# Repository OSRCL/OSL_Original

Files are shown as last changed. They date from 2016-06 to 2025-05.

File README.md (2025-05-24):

# Open Source RC Lights
(aka, "OSL")

OSL Board Assembled OSL Board

**--> [INSTRUCTIONS & DOCUMENTATION AVAILABLE HERE](https://openpanzer.org/wiki/doku.php?id=wiki:otherprojects:osl) <--**

OSL is an Arduino-based, open source project for controlling lights in RC cars and trucks. It uses an ATmega328 as the processor and has 8 light outputs. All the components on the board are through-hole which makes it easy to assemble and solder. 
 
Some features: 
  * Control up to 8 light circuits
  * Accepts three channels of RC input (throttle, steering, and an optional 3rd channel)
  * Each light can respond to various model **States**: forward, reverse, stopped, stopped after delay, braking, right turn, left turn, no turn, accelerating, decelerating, and any of up to 5 positions for the channel 3 switch if attached. 
  * For each light in each State the **Setting** defines the behavior of the light: on, off, fade on, fade off, blink, fast blink, safety blink (and the alternate versions of blink, fast blink, and safety blink), soft blink, dim, xenon-on effect, or backfire effect.
  * The collection of all Settings for all lights in all States is called a **Scheme**. Multiple schemes can be defined and you can switch between them from your transmitter.
  * Schemes and other operating adjustments are made in the free Arduino IDE. Everything is well explained and you don't need to know how to write code.
  * Works with both 5 and 6 volt RC systems
<br/>

## Resources  
  * [OSL Wiki](https://openpanzer.org/wiki/doku.php?id=wiki:otherprojects:osl)
  * [RC Groups Discussion Thread](http://www.rcgroups.com/forums/showthread.php?t=1539753)
  * [Complete collection of resources and downloads](https://openpanzer.org/downloads#OSL)
<br/>

## OSL Hardware
**Board version 1.7**  
See the "hardware" folder in this repository for Eagle board files, schematic, and bill of materials. 
  * [Printable Schematic](https://www.openpanzer.org/secure_downloads/osl/eagle/OpenSourceLights_v17_Schematic.pdf) (PDF)
  * [Bill of Materials](https://www.openpanzer.org/secure_downloads/osl/bom/OpenSourceLights_BOM.pdf) (PDF)
  * [Purchase PCBs at OSH Park](https://oshpark.com/shared_projects/kmCzNipk)
  * [Other user designs](https://www.openpanzer.org/forum/index.php?page=osl_other)
<br/>

## Getting Started with Arduino
First you will need to install the Arduino IDE on your computer, [you can download it from here](https://www.arduino.cc/en/software).

Next download the OSL source files (Arduino calls this a "sketch"). Click the green "Clone or Download" button at the top of this page, then select "Download ZIP." 

1. Unzip the download and put the folder named “OpenSourceLights” into your Arduino “Sketches” folder. This may be a location you specified or it may be the default location that Arduino chose when you installed the IDE. If you are unsure where Arduino thinks your Sketches folder is:
   - Open the Arduino IDE
   - Go to File -> Preferences
   - At the top of the popup screen that appears, look at the path under the heading "Sketchbook location". This shows you where your Sketches folder is. 

2. Open the sketch through the IDE or just by clicking on any of the .ino files in the OpenSourceLights folder. Now let's make sure the IDE is setup to compile the project correctly:
   - In the IDE, go to the Tools menu and select Board -> Arduino AVR Boards -> "Arduino Nano." In fact several boards would work, but "Nano" is the easiest to remember.
   - Make sure we have the correct processor selected. Go to Tools -> Processor -> and select "ATmega328P". **Note:** Some users may need to select "Atmega328P (Old Bootloader)" if they have problems loading the sketch onto their device.

3. Compile. This is done by clicking the checkmark button at the top left of the IDE window, or by going to the Sketch menu and clicking "Verify/Compile." The IDE will run for a few moments then give you the results of the compilation at the bottom of the screen. If successful, you are ready to modify the sketch so that it does what you want! Read this page in the OSL Wiki for more information: [Modifying the Sketch](https://openpanzer.org/wiki/doku.php?id=wiki:otherprojects:osl:sketch)

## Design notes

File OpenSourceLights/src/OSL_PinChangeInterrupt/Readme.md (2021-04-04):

PinChangeInterrupt Library 1.2.8
================================

Header Picture

PinChangeInterrupt library with a resource friendly implementation (API and LowLevel).
PinChangeInterrupts are different than normal Interrupts. See detail below.

##### Features:
* PinChangeInterrupt for a lot of pins
* Rising, Falling or Change detection for every pin separately
* Usable on a lot Arduino compatible boards
* Implementation is fast, compact and resource friendly
* Ports/Pins can be manually deactivated in the Settings file
* API and LowLevel option
* Full Port0-3 support
* .a linkage optimization (Arduino IDE)

<a href="https://www.buymeacoffee.com/nicohood">Buy Me A Coffee</a>

#### Supported pins for PinChangeInterrupt:
See [PCINT pin table](https://github.com/NicoHood/PinChangeInterrupt/#pinchangeinterrupt-table) at the bottom for more details.

```
Arduino Uno/Nano/Mini: All pins are usable
Arduino Mega: 10, 11, 12, 13, 50, 51, 52, 53, A8 (62), A9 (63), A10 (64),
           A11 (65), A12 (66), A13 (67), A14 (68), A15 (69)
Arduino Leonardo/Micro: 8, 9, 10, 11, 14 (MISO), 15 (SCK), 16 (MOSI)
HoodLoader2: All (broken out 1-7) pins are usable
Attiny 24/44/84: All pins are usable
Attiny 25/45/85: All pins are usable
Attiny 13: All pins are usable
Attiny 441/841: All pins are usable
ATmega644/ATmega644P/ATmega1284P: All pins are usable
ATmega 162: PORTA and PORTC usable
```

Contact information can be found here:

www.nicohood.de

Installation
============

Download the zip, extract and remove the "-master" of the folder.
Install the library [as described here](http://arduino.cc/en/pmwiki.php?n=Guide/Libraries).

This library can also be used with the [DMBS AVR Library Collection](https://github.com/NicoHood/avr) and a pure makefile.

How to use
==========

It is important that you know at least the basic difference between **PinInterrupts** and **PinChangeInterrupts**.
I will explain the basics of **PinChangeInterrupts** (PCINTs) based on an Arduino Uno.

On a standard Arduino Uno Pin 2 and 3 have **PinInterrupts**. Those are exclusively for a single pin and can detect RISING, FALLING and CHANGE.

**PinChangeInterrupts** instead are used for a whole port (they should have better named them PortChangeInterrupts) and can only detect CHANGE for a whole port.
Each pin row (0-7, 8-13, A0-A5) represents a port. If an interrupt (ISR) occurs on one pin of a port
it is still unclear what pin of the port caused this interrupt. Therefore this library saves the state of the whole port and compares with the last state.
This way we can also see if it was a RISING or FALLING edge instead of only knowing the CHANGE.

A **PinChangeInterrupt** will only be triggered for the attached pins per port.
Meaning if you set PCINT for a pin and another pin on the same port is changing a lot
it will not interrupt your code.

**PinChangeInterrupts** might be a tiny bit slower and not that reliable because of that detection overhead (talking about micro seconds).
Make sure to not use longer function calls inside the ISR or Serial print.
You have the same issues on normal **PinInterrupts** and interrupts in general.

The library is coded to get maximum speed and minimum code size. The LowLevel example without the API takes 4uS to enter the interrupt function in the worst case
which is pretty good and might be even better than the **PinInterrupt** code from the official Arduino core due to high optimization.
If you need very precise interrupts you better use **PinInterrupts** without the Arduino IDE at all.

### Examples
To see how the code works just check the Led and TickTock example.
The LowLevel example is for advanced users with more optimization and more direct access.
The HowItWorks example shows the basic PinChangeInterrupt setup and decoding routine, similar to the library.
See the notes in the examples about more details.

An useful "real use" example of the PinChangeInterrupt library can be found here:
https://github.com/NicoHood/IRLremote

### API Reference

##### Attach a PinChangeInterrupt
```cpp
// The pin has to be a PCINT number. Use the makro to convert a pin to a PCINT number.
// Enables event functions which need to be defined in the sketch.
// Valid interrupt modes are: RISING, FALLING or CHANGE
attachPinChangeInterrupt(digitalPinToPinChangeInterrupt(pinTick), tick, RISING);

// You can also input the PCINT number (see table below)
attachPinChangeInterrupt(5, tock, FALLING);

// PinChangeInterrupt can always be abbreviated with PCINT
attachPCINT(digitalPinToPCINT(pinBlink), blinkLed, CHANGE);
```

##### Detach a PinChangeInterrupt
```cpp
// Similar usage as the attachPCINT function.
// Interrupts will no longer occur.
detachPinChangeInterrupt(digitalPinToPinChangeInterrupt(pinTick));
detachPinChangeInterrupt(5);
detachPCINT(digitalPinToPCINT(pinTock));
```

##### Enable/Disable a PinChangeInterrupt
```cpp
// Similar usage as the attachPCINT function.
// Use this to temporary enable/disable the Interrupt
disablePinChangeInterrupt(digitalPinToPinChangeInterrupt(pinTick));
disablePinChangeInterrupt(5);
disablePCINT(digitalPinToPCINT(pinBlink));

// Enable the PCINT with the old settings again (function + mode)
enablePinChangeInterrupt(digitalPinToPinChangeInterrupt(pinTick));
enablePinChangeInterrupt(5);
enablePCINT(digitalPinToPCINT(pinBlink));
```

##### Get Trigger on mode CHANGE
```cpp
// Differenciate between RISING and FALLING on mode CHANGE.
// Only use this in the attached interrupt function.
uint8_t trigger = getPinChangeInterruptTrigger(digitalPinToPCINT(pinTick));
if(trigger == RISING)
  // Do something
else if(trigger == FALLING)
  // Do something
else
  // Wrong usage (trigger == CHANGE)
```

##### LowLevel API
See [LowLevel example](examples/PinChangeInterrupt_LowLevel/PinChangeInterrupt_LowLevel.ino) for more details.
```cpp
// Use the attach function as you are used to, just leave out the function name
attachPinChangeInterrupt(interruptBlink, CHANGE);

// LowLevel function that is called when an interrupt occurs for a specific PCINT.
// It is required to know the exact PCINT number, no Arduino pin number will work here.
void PinChangeInterruptEvent(5)(void) {
  // Do something
}
```

PinchangeInterrupt Table
========================
Pins with * are not broken out/deactivated by default.
You may activate them in the setting file (advanced).

Each row section represents a port(0-3).
Not all MCUs have all Ports/Pins physically available.

#### Official Arduinos
```
| PCINT |  Uno/Nano/Mini  |   Mega/2560    | Leonardo/Micro | HL2 (8/16/32u2) |
| ----- | --------------- | -------------- | -------------- | --------------- |
|     0 |  8       (PB0)  | 53 SS   (PB0)  |    SS   (PB0)* |  0 SS   (PB0)*  |
|     1 |  9       (PB1)  | 52 SCK  (PB1)  |    SCK  (PB1)  |  1 SCK  (PB1)   |
|     2 | 10 SS    (PB2)  | 51 MOSI (PB2)  |    MOSI (PB2)  |  2 MOSI (PB2)   |
|     3 | 11 MISO  (PB3)  | 50 MISO (PB3)  |    MISO (PB3)  |  3 MISO (PB3)   |
|     4 | 12 MOSI  (PB4)  | 10      (PB4)  |  8/A8   (PB4)  |  4      (PB4)   |
|     5 | 13 SCK   (PB5)  | 11      (PB5)  |  9/A9   (PB5)  |  5      (PB5)   |
|     6 |    XTAL1 (PB6)* | 12      (PB6)  | 10/A10  (PB6)  |  6      (PB6)   |
|     7 |    XTAL2 (PB7)* | 13      (PB7)  | 11      (PB7)  |  7      (PB7)   |
| ----- | --------------- | -------------- | -------------- | --------------- |
|     8 | A0       (PC0)  |  0 RX   (PE0)* |                |         (PC6)*  |
|     9 | A1       (PC1)  | 15 RX3  (PJ0)* |                |         (PC5)*  |
|    10 | A2       (PC2)  | 14 TX3  (PJ1)* |                |         (PC4)*  |
|    11 | A3       (PC3)  |    NC   (PJ2)* |                |         (PC2)*  |
|    12 | A4 SDA   (PC4)  |    NC   (PJ3)* |                |         (PD5)*  |
|    13 | A5 SDC   (PC5)  |    NC   (PJ4)* |                |                 |
|    14 |    RST   (PC6)* |    NC   (PJ5)* |                |                 |
|    15 |                 |    NC   (PJ6)* |                |                 |
| ----- | --------------- | -------------- | -------------- | --------------- |
|    16 |  0 RX    (PD0)  | A8      (PK0)  |                |                 |
|    17 |  1 TX    (PD1)  | A9      (PK1)  |                |                 |
|    18 |  2 INT0  (PD2)  | A10     (PK2)  |                |                 |
|    19 |  3 INT1  (PD3)  | A11     (PK3)  |                |                 |
|    20 |  4       (PD4)  | A12     (PK4)  |                |                 |
|    21 |  5       (PD5)  | A13     (PK5)  |                |                 |
|    22 |  6       (PD6)  | A14     (PK6)  |                |                 |
|    23 |  7       (PD7)  | A15     (PK7)  |                |                 |
| ----- | --------------- | -------------- | -------------- | --------------- |
```

#### Atmel Attinys
```
| PCINT |   Attiny13   |    Attiny x4    |   Attiny x5   |     Attiny x41      |
| ----- | ------------ | --------------- | ------------- | ------------------- |
|     0 | 0 MOSI (PB0) |  0       (PA0)  | 0 MOSI  (PB0) | A0/D0         (PA0) |
|     1 | 1 MISO (PB1) |  1       (PA1)  | 1 MISO  (PB1) | A1/D1         (PA1) |
|     2 | 2 SCK  (PB2) |  2       (PA2)  | 2 SCK   (PB2) | A2/D2         (PA2) |
|     3 | 3      (PB3) |  3       (PA3)  | 3 XTAL1 (PB3) | A3/D3         (PA3) |
|     4 | 4      (PB4) |  4 SCK   (PA4)  | 4 XTAL2 (PB4) | A4/D4         (PA4) |
|     5 | 5 RST  (PB5) |  5 MISO  (PA5)  | 5 RST   (PB5) | A5/D5   PWM   (PA5) |
|     6 |              |  6 MOSI  (PA6)  |               | A7/D7   PWM   (PA6) |
|     7 |              |  7       (PA7)  |               | A6/D6   PWM   (PA7) |
| ----- | ------------ | --------------- | ------------- | ------------------- |
|     8 |              | 10 XTAL1 (PB0)* |               | A10/D10 XTAL1 (PB0) |
|     9 |              |  9 XTAL2 (PB1)* |               | A9/D9   XTAL2 (PB1) |
|    10 |              |  8 INT0  (PB2)* |               | A8/D8   PWM   (PB2) |
|    11 |              |    RST   (PB3)* |               |         RST   (PB3) |
|    12 |              |                 |               |                     |
|    13 |              |                 |               |                     |
|    14 |              |                 |               |                     |
|    15 |              |                 |               |                     |
| ----- | ------------ | --------------- | ------------- | ------------------- |
```

#### Other Atmel MCUs
```
| PCINT | ATmega644P/1284P  |
| ----- | ----------------- |
|     0 | A0/D24      (PA0) |
|     1 | A1/D25      (PA1) |
|     2 | A2/D26      (PA2) |
|     3 | A3/D27      (PA3) |
|     4 | A4/D28      (PA4) |
|     5 | A5/D29      (PA5) |
|     6 | A6/D30      (PA6) |
|     7 | A7/D31      (PA7) |
| ----- | ----------------- |
|     8 |  0          (PB0) |
|     9 |  1          (PB1) |
|    10 |  2 INT2     (PB2) |
|    11 |  3 PWM      (PB3) |
|    12 |  4 SS/PWM   (PB4) |
|    13 |  5 MOSI/PWM (PB5) |
|    14 |  6 MISO/PWM (PB6) |
|    15 |  7 SCK      (PB7) |
| ----- | ----------------- |
|    16 | 16 SCL      (PC0) |
|    17 | 17 SDA      (PC1) |
|    18 | 18 TCK      (PC2) |
|    19 | 19 TMS      (PC3) |
|    20 | 20 TDO      (PC4) |
|    21 | 21 TDI      (PC5) |
|    22 | 22          (PC6) |
|    23 | 23          (PC7) |
| ----- | ----------------- |
|    24 |  8 RX0      (PD0) |
|    25 |  9 TX0      (PD1) |
|    26 | 10 RX1/INT0 (PD2) |
|    27 | 11 TX1/INT1 (PD3) |
|    28 | 12 PWM      (PD4) |
|    29 | 13 PWM      (PD5) |
|    30 | 14 PWM      (PD6) |
|    31 | 15 PWM      (PD7) |
| ----- | ----------------- |
```

Developer Information
=====================
If a PinChangeInterrupt occurs it will determine the triggered pin(s).
The library uses weak callback functions that are called for the triggered pins(s).
This way we can easily skip not triggered pins (I looked at the assembler) and also implement a fast LowLevel version.

Also the order of the function execution is (normally) ordered from the lower pin number to the higher.
Meaning pin 8 will be checked faster as pin 13 (Arduino Uno). Talking about micro seconds here! You can change the order in the settings.
For example by default pin 0-3 have a low priority order than pin 4-7 (Arduino Uno). Because they are used for Serial and normal PinInterrupts.
I don't expect anyone to use those pins at all with PCINT but at least the priority is lowered compared to the other pins.

The API takes those weak functions and just overwrites all of them and call the function pointers of the attached functions instead.
This way the function can be changed at runtime and its also easier to integrate into other libraries.
The function pointers take a bit flash though (LowLevel: 1526/18, API: 1790/58 for Led example).

You can get better performance and less code size if you deactivate the not used pins/ports manually in the settings file.
This way only the needed pins get compiled and the code is optimized by the preprocessor.
For a bit more comfortable/automatic optimization you can [install the library into the core](https://github.com/NicoHood/PinChangeInterrupt/#optional-installation)
to get use of the .a linkage. This way only the used ports get compiled.
So if you only use pins on a single port (eg 8-13) then only this port gets compiled. This only works with the core installation.

That's it! I hope you like the library. I tried to make it as simple and small as possible.
Keep in mind that PCINTs are not useful for every project but in most cases
the new PinChangeInterrupts may help you a lot.

Version History
===============
```
1.2.8 Release (22.11.2020)
* Add support for ATmega644 #34

1.2.7 Release (07.10.2018)
* Add support for ATmega162 #21

1.2.6 Release (10.02.2018)
* Fix makefile compilation problems

1.2.5 Release (02.09.2017)
* Fixed makefile compilation
* Added support to disable pcint/port via -DPCINT_DISABLE_PORT0 etc.
* Added ATtinyX313 support
* Fix ATmega1284P

1.2.4 Release (16.04.2016)
* Fixed Attinyx4/x5 Issue #8

1.2.3 Release (24.12.2015)
* Added Attiny441/841 support

1.2.2 Release (05.12.2015)
* Fixed initial value when enabled issue
* Enabled official dot_a_linkage
* Added Attiny13 support Issue #4
* Updated documentation
* Improved detaching function
* Improved attaching and enabling

1.2.1 Release (24.05.2015)
* Fix Attiny Issue #1
* Added enable/disable function
* Added getPinChangeInterruptTrigger() function
* Added to Arduino IDE library manager

1.2 Release (19.04.2015)
* Added weak interrupt function
* Improved interrupt function calls
* Fixed attach/detach array position when ports are deactivated
* Improved manual PCINT deactivation by user
* Improved definitions for different boards
* HoodLoader2 definition fixes
* Improved speed
* Improved specific boards
* Moved attach function to .cpp file
* Updated examples
* Added API and LowLevel
* Added Port3 support (ATmega644P/ATmega1284P)
* Added PCINT_VERSION definition

1.1 Release (06.12.2014)
* Added port deactivation
* Ram usage improvements for AVRs with <3 PCINT ports

1.0 Release (04.12.2014)
* Added general PinChangeInterrupt functions
* Added support for most Arduino boards
* Added basic example
* Added an example with IRLremote
```

License and Copyright
=====================
If you use this library for any cool project let me know!

```
Copyright (c) 2014-2018 NicoHood
See the readme for credit to other people.

Permission is hereby granted, free of charge, to any person obtaining a copy
of this software and associated documentation files (the "Software"), to deal
in the Software without restriction, including without limitation the rights
to use, copy, modify, merge, publish, distribute, sublicense, and/or sell
copies of the Software, and to permit persons to whom the Software is
furnished to do so, subject to the following conditions:

The above copyright notice and this permission notice shall be included in
all copies or substantial portions of the Software.

THE SOFTWARE IS PROVIDED "AS IS", WITHOUT WARRANTY OF ANY KIND, EXPRESS OR
IMPLIED, INCLUDING BUT NOT LIMITED TO THE WARRANTIES OF MERCHANTABILITY,
FITNESS FOR A PARTICULAR PURPOSE AND NONINFRINGEMENT. IN NO EVENT SHALL THE
AUTHORS OR COPYRIGHT HOLDERS BE LIABLE FOR ANY CLAIM, DAMAGES OR OTHER
LIABILITY, WHETHER IN AN ACTION OF CONTRACT, TORT OR OTHERWISE, ARISING FROM,
OUT OF OR IN CONNECTION WITH THE SOFTWARE OR THE USE OR OTHER DEALINGS IN
THE SOFTWARE.
```

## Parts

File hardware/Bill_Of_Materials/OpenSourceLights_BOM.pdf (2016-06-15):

Open Source Lights - RC Light Controller
| Manufacturer | Retailer
| Schematic Part | Manufacturer Item Description | | Part Number | Part Number | Price Ea. | Qty | Notes
| IC1 | Atmel | Arduino bootloader-programmed Atmega328P | | 123 (http://www.adafruit.com/products/123) | $5.95 | 1 | Recommended - bootloader already installed - Purchase from Adafruit
Alternate | IC1 | Atmel | MCU AVR 32K FLASH 28-PDIP | ATMEGA328P-PU | ATMEGA328P-PU-ND (http://search.digikey.com/us/en/products/ATMEGA328P-PU/ATMEGA328P-PU-ND/1914589) | $4.98 | 1 | This one needs an Arduino bootloader installed before placing on board
| - | 3M | SOCKET IC OPEN FRAME 28POS .3" | 4828-3004-CP | 3M5480-ND (http://www.digikey.com/product-search/en?KeyWords=3M5480-ND) | $0.77 | 1 | Optional (but recommended) Atmega socket - allows removal of the chip if necessary
| Y1 | TXC Corp | CRYSTAL 16.000 MHZ 18PF HC49US | 9B-16.000MAAJ-B | 887-1019-ND (http://search.digikey.com/scripts/DkSearch/dksus.dll?Detail&name=887-1019-ND) | $0.46 | 1 | Crystal
| C1-C2 | Kemet | CAP 22PF 200V 5% CER RADIAL | C315C220J2G5TA | 399-4162-ND (http://search.digikey.com/scripts/DkSearch/dksus.dll?Detail&name=399-4162-ND) | $0.43 | 2 | 22pf caps for crystal
| C3-C5 | Kemet | CAP .1UF 50V 20% CER RADIAL | C315C104M5U5TA | 399-4151-ND (http://search.digikey.com/scripts/DkSearch/dksus.dll?Detail&name=399-4151-ND) | $0.30 | 3 | Bypass caps - VCC, ARef, DTR Reset
| C6 | Nichicon | CAP ALUM 220UF 50V 20% RADIAL | UVZ1H221MPD | 493-1342-ND (http://search.digikey.com/scripts/DkSearch/dksus.dll?vendor=0&keywords=493-1342) | $0.47 | 1 | Power supply cap
| D1 | Fairchild | DIODE SS FAST 100V 200MA DO35 | 1N4148TA | 1N4148TACT-ND (http://search.digikey.com/us/en/products/1N4148TA/1N4148TACT-ND/1532747) | $0.14 | 1 | Voltage drop diode - keeps Atmega near 5v even in 6v system
| T1-T8 | Fairchild | TRANS NPN 45V 0.8A TO-92 | BC33725TA | BC33725TACT-ND (http://www.digikey.com/product-search/en?KeyWords=BC33725TACT-ND) | $0.21 | 8 | BC337 NPN transistors, TO92
| RC & FTDI Header | Samtec | CONN HEADER 15POS .100" SGL GOLD | TSW-115-23-L-S | SAM1071-15-ND (http://search.digikey.com/us/en/products/TSW-115-23-L-S/SAM1071-15-ND/1103411) | $1.19 | 1 | Male break-away headers for RC inputs and FTDI cable
Choose | Light 1-8 sockets | JST | CONN HEADER PH SIDE 2POS 2MM | S2B-PH-K-S(LF)(SN) | 455-1719-ND (http://search.digikey.com/scripts/DkSearch/dksus.dll?vendor=0&keywords=455-1719) | $0.98 | 8 | JST male sockets - right angle. (Price for 10)
One | Light 1-8 sockets | JST | CONN HEADER PH TOP 2POS 2MM | B2B-PH-K-S(LF)(SN) | 455-1704-ND (http://search.digikey.com/scripts/DkSearch/dksus.dll?vendor=0&keywords=455-1704) | $0.99 | 8 | JST male sockets - vertical. (Price for 10)
| R1-R8 | Yageo | RES 562 OHM 1/4W 1% AXIAL | MFR-25FBF52-562R | 562XBK-ND (http://www.digikey.com/product-search/en?KeyWords=562XBK-ND) | $0.84 | 8 | Base resistors (Price for 10)
| R9-R10 | Yageo | RES 221 OHM 1/4W 1% METAL FILM | MFR-25FBF-221R | 221XBK-ND (http://search.digikey.com/us/en/products/MFR-25FBF-221R/221XBK-ND/12863) | $0.50 | 2 | Resistors. (Price for 5)
| R11-18 | Yageo | RES 100 OHM 1/4W 1% METAL FILM | MFR-25FBF-100R | 100XBK-ND (http://search.digikey.com/scripts/DkSearch/dksus.dll?Detail&name=100XBK-ND) | $0.84 | 8 | LED current-limiting resistors: OR CHOOSE YOUR OWN VALUES
| R19 | Yageo | RES 10.0K OHM 1/4W 1% METAL FILM | MFR-25FBF-10K0 | 10.0KXBK-ND (http://search.digikey.com/scripts/DkSearch/dksus.dll?Detail&name=10.0KXBK-ND) | $0.63 | 1 | 10k Reset pull-up resistor. (Price for 5)
| Red LED | Panasonic | LED RED DIFFUSED 3MM ROUND | LN28RCPX | P606-ND (http://search.digikey.com/us/en/cat/optoelectronics/leds-75ma-discrete/524729?k=P606-ND) | $0.40 | 1 | 3mm red indicator LED
| Green LED | Panasonic | LED GREEN DIFFUSED 3MM ROUND | LN38GCPX | P607-ND (http://search.digikey.com/us/en/products/LN38GCPX/P607-ND/644227) | $0.42 | 1 | 3mm green indicator LED
| S1 | TE Conn. | SWITCH TACTILE SPST-NO 0.05A 24V | 1825910-6 | 450-1650-ND (http://www.digikey.com/product-detail/en/1825910-6/450-1650-ND/1632536) | $0.11 | 1 | Pushbutton - standard 6x6mm outline tactille switch, 5mm actuator height off board

NOTES ABOUT SERIES RESISTORS FOR LEDs:
Series resistors for the off-board LEDs can be tailored to fit the LEDs in use. Typically the LEDs available in the RC Car market today come in a string of two LEDs per cable, wired in parallel.
Unfortunately specs are rarely listed for any of these products. Testing has found that a series resistor of 100 ohms is almost always adequate for these arrangements, even if operating at 6 volts.

If you wish to maximize the light output you may go to a lower resistor, say 75 or even 50 ohms. However be sure to measure current draw with a meter - you shouldn't usually exceed 20mAh per LED, which would be 40mAh total for a string of two LEDs in parallel.

If you want to be extra safe, a 150 ohm resistor could be used.

If you make your own LED strings or know the specs of the LED you are using, you can calculate the resistor value precisely using free online calculators,
such as this one: | Led Resistor Calculator (http://ledz.com/?p=zz.led.resistor.calculator)

NOTES ABOUT SOURCES FOR LEDs:
The least expensive LEDs that already come soldered to cable assemblies with JST plugs are the ones from YeahRacing (series LK-0008 for 3mm LEDs, LK-0009 for 5mm LEDs) 3Racing brand LEDs will also work as will the Tamiya LEDs, though the Tamiyas are overpriced and require different resistors (often lower than 100 ohms)
The YeahRacingt lights can be purchased in many places, my favorite is RCMart. Here is there YeahRacing LED list: | RCMart YeahRacing LEDs (http://www.rcmart.com/body-light-font-colorredblight-rcbfont-c-438_900.html)
At the time of writing they were about $3 for a string of 2 LEDs.

NOTES ABOUT MAKING YOUR OWN LED CABLE ASSEMBLIES:
If you have your own LEDs and want to make your own cable assemblies, you will need some thin gauge wire and the female JST plugs and pins. You can find pre-assembled plugs with pigtails on eBay,
do a search for something like "PH 2.0mm Female Connector Wire". Here is a link which probably won't remain active forever: | | | eBay PH Pigtails (http://www.ebay.com/itm/50-pcs-PH-2-0mm-Pitch-2-Pin-Female-Connector-with-26AWG-300mm-Leads-Cable-/400670372199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) | | (50 leads for ~$9 shipped!)
But if you really want to make your own, here are part numbers at DigiKey:
Note: you can easily find wire for cheaper than this - use old servo extensions, strip it from old mouse/network cables, whatever…
Note: crimping these miniature connectors is not very easy. Buying pre-made is recommended.
| | Manufacturer | DigiKey
| Manufacturer DigiKey Description | | Part Number | Part Number | Price Ea. | | Notes
| JST | CONN HOUSING PH 2POS 2MM WHITE | PHR-2(P) | 455-1165-ND (http://search.digikey.com/scripts/DkSearch/dksus.dll?vendor=0&keywords=455-1165) | $0.05 | | This is the female JST plug that will mate with the connectors on the board.
JST | CONN TERM CRIMP PH 24-30AWG | SPH-002T-P0.5S | 455-1127-1-ND (http://search.digikey.com/scripts/DkSearch/dksus.dll?Detail&name=455-1127-1-ND) | $0.29 | | These are the crimp terminals for the female connectors. (Price for 10)
Alpha Wire | HOOK-UP WIRE 26AWG STRAND RED | 3049 RD005 | A3049R-100-ND (http://search.digikey.com/scripts/dksearch/dksus.dll?vendor=0&keywords=a3049r-100-nd) | $16.25 | | 26 AWG red hookup wire in 100 foot spool. You can probably find cheaper wire elsewhere.
Alpha Wire | HOOK-UP WIRE 26AWG STRAND BLACK | 3049 BK005 | A3049B-100-ND (http://search.digikey.com/scripts/dksearch/dksus.dll?vendor=0&keywords=A3049B-100-ND) | $16.25 | | 26 AWG black hookup wire in 100 foot spool. You can probably find cheaper wire elsewhere.

If you need a crimping tool, Hansen Hobbies sells an inexpensive (~$15) one that will work on these JST pins as well as allow you to make your own servo extensions:
Hansen Hobbies Economy Crimping Tool (http://www.hansenhobbies.com/products/connectors/tools/crimp_ec/)

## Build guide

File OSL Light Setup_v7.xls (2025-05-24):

DIFFERENT POSSIBLE SETTINGS |  |  |  |  |  |  |  | THIS FILE IS FOR OSL FIRMWARE VERSIONS 7.x
NA | Do nothing
ON
OFF
FADEON | Fades on slowly
FADEOFF | Fades off slowly
BLINK | Will blink at the rate set in UserConfig.h (BlinkInterval)
BLINK_ALT | Same as blink, except alternating
FASTBLINK | Will blink at the fast rate set in UserConfig.h
FASTBLINK_ALT | Same as fast blink, except alternating
SOFTBLINK | Will blink at the rate set in UserConfig.h (BlinkInterval), but the light will fade-in and fade-out. The timing of the fade can be adjusted, see UserConfig
DIM | Will dim to the level set in UserConfig.h
XENON | Turns a light on but with a special effect that looks like a xenon bulb turning on
BACKFIRE | Special effect that blinks a light randomly for a short period of time (only works under Decelerating state - use for tailpipe LEDs)
SAFETYBLINK | A series of blinks (the number can be defined on AA_UserConfig.h), followed by a pause while the same number of blinks occurs on the ALT side.
SAFETYBLINK_ALT | The alternate side of SAFETYBLINK, it will blink when SAFETYBLINK is off, and SAFETYBLINK will blink when SAFETYBLINK_ALT is off. Used on emergency vehicles.
NUMBER OF OUTPUT CHANNELS
Choose the number of channels your OSL board is setup for (no more than 8). Settings applied to channel numbers greater than the number entered here will be stripped from the exported schemes.
8
AA LIGHT SETUP PATH
Use "Select File" to select an existing AA_Light_Setup.ino file you wish to replace. "Generate Setup File" will update the file, or create it from scratch if it doesn't exist. Re-/open the file in the arduino IDE after the file is generated, then flash to board.
C:\Users\nick\Desktop\OpenSourceLights\AA_LightSetup.ino
SCHEMES SETUP
Click on the 'DON'T USE' to change it 'USE' to include it in the setup file and vice versa.
Changes of the channel names in Scheme 1 are reflected in the others.
SCHEME 1 | USE |  |  |  | TITLE: | no title
 | Pos 1 | Pos 2 | Pos 3 | Pos 4 | Pos 5 | Forward | Reverse | Stop | StopDelay | Brake | Right Turn | Left Turn | No Turn | Accelerating | Decelerating
channel 1 | OFF | OFF | OFF | OFF | OFF | NA | NA | NA | NA | NA | NA | NA | NA | NA | NA
channel 2 | OFF | XENON | OFF | OFF | OFF | ON | BACKFIRE | NA | NA | NA | NA | NA | NA | NA | NA
channel 3 | SAFETYBLINK_ALT | OFF | OFF | FASTBLINK_ALT | OFF | NA | NA | NA | NA | NA | NA | NA | NA | NA | NA
channel 4 | OFF | OFF | OFF | OFF | OFF | NA | NA | NA | NA | NA | NA | NA | NA | NA | NA
channel 5 | OFF | OFF | OFF | FASTBLINK | OFF | NA | NA | NA | NA | NA | NA | NA | NA | NA | NA
channel 6 | SAFETYBLINK | OFF | OFF | OFF | OFF | NA | NA | NA | NA | NA | NA | NA | NA | NA | NA
channel 7 | OFF | OFF | OFF | OFF | OFF | NA | NA | NA | NA | NA | NA | NA | NA | NA | NA
channel 8 | OFF | OFF | OFF | OFF | OFF | NA | NA | NA | NA | NA | NA | NA | NA | NA | NA
SCHEME 2 | DON'T USE |  |  |  | TITLE: | no title
 | Pos 1 | Pos 2 | Pos 3 | Pos 4 | Pos 5 | Forward | Reverse | Stop | StopDelay | Brake | Right Turn | Left Turn | No Turn | Accelerating | Decelerating
channel 1 | OFF | OFF | OFF | OFF | OFF | NA | NA | NA | NA | NA | NA | NA | NA | NA | NA
channel 2 | OFF | OFF | OFF | OFF | OFF | NA | NA | NA | NA | NA | NA | NA | NA | NA | NA
channel 3 | OFF | OFF | OFF | OFF | OFF | NA | NA | NA | NA | NA | NA | NA | NA | NA | NA
channel 4 | OFF | OFF | OFF | OFF | OFF | NA | NA | NA | NA | NA | NA | NA | NA | NA | NA
channel 5 | OFF | OFF | OFF | OFF | OFF | NA | NA | NA | NA | NA | NA | NA | NA | NA | NA
channel 6 | OFF | OFF | OFF | OFF | OFF | NA | NA | NA | NA | NA | NA | NA | NA | NA | NA
channel 7 | OFF | OFF | OFF | OFF | OFF | NA | NA | NA | NA | NA | NA | NA | NA | NA | NA
channel 8 | OFF | OFF | OFF | OFF | OFF | NA | NA | NA | NA | NA | NA | NA | NA | NA | NA
SCHEME 3 | DON'T USE |  |  |  | TITLE: | no title
 | Pos 1 | Pos 2 | Pos 3 | Pos 4 | Pos 5 | Forward | Reverse | Stop | StopDelay | Brake | Right Turn | Left Turn | No Turn | Accelerating | Decelerating
channel 1 | OFF | OFF | OFF | OFF | OFF | NA | NA | NA | NA | NA | NA | NA | NA | NA | NA
channel 2 | OFF | OFF | OFF | OFF | OFF | NA | NA | NA | NA | NA | NA | NA | NA | NA | NA
channel 3 | OFF | OFF | OFF | OFF | OFF | NA | NA | NA | NA | NA | NA | NA | NA | NA | NA
channel 4 | OFF | OFF | OFF | OFF | OFF | NA | NA | NA | NA | NA | NA | NA | NA | NA | NA
channel 5 | OFF | OFF | OFF | OFF | OFF | NA | NA | NA | NA | NA | NA | NA | NA | NA | NA
channel 6 | OFF | OFF | OFF | OFF | OFF | NA | NA | NA | NA | NA | NA | NA | NA | NA | NA
channel 7 | OFF | OFF | OFF | OFF | OFF | NA | NA | NA | NA | NA | NA | NA | NA | NA | NA
channel 8 | OFF | OFF | OFF | OFF | OFF | NA | NA | NA | NA | NA | NA | NA | NA | NA | NA
SCHEME 4 | DON'T USE |  |  |  | TITLE: | no title
 | Pos 1 | Pos 2 | Pos 3 | Pos 4 | Pos 5 | Forward | Reverse | Stop | StopDelay | Brake | Right Turn | Left Turn | No Turn | Accelerating | Decelerating
channel 1 | OFF | OFF | OFF | OFF | OFF | NA | NA | NA | NA | NA | NA | NA | NA | NA | NA
channel 2 | OFF | OFF | OFF | OFF | OFF | NA | NA | NA | NA | NA | NA | NA | NA | NA | NA
channel 3 | OFF | OFF | OFF | OFF | OFF | NA | NA | NA | NA | NA | NA | NA | NA | NA | NA
channel 4 | OFF | OFF | OFF | OFF | OFF | NA | NA | NA | NA | NA | NA | NA | NA | NA | NA
channel 5 | OFF | OFF | OFF | OFF | OFF | NA | NA | NA | NA | NA | NA | NA | NA | NA | NA
channel 6 | OFF | OFF | OFF | OFF | OFF | NA | NA | NA | NA | NA | NA | NA | NA | NA | NA
channel 7 | OFF | OFF | OFF | OFF | OFF | NA | NA | NA | NA | NA | NA | NA | NA | NA | NA
channel 8 | OFF | OFF | OFF | OFF | OFF | NA | NA | NA | NA | NA | NA | NA | NA | NA | NA
SCHEME 5 | DON'T USE |  |  |  | TITLE: | no title
 | Pos 1 | Pos 2 | Pos 3 | Pos 4 | Pos 5 | Forward | Reverse | Stop | StopDelay | Brake | Right Turn | Left Turn | No Turn | Accelerating | Decelerating
channel 1 | OFF | OFF | OFF | OFF | OFF | NA | NA | NA | NA | NA | NA | NA | NA | NA | NA
channel 2 | OFF | OFF | OFF | OFF | OFF | NA | NA | NA | NA | NA | NA | NA | NA | NA | NA
channel 3 | OFF | OFF | OFF | OFF | OFF | NA | NA | NA | NA | NA | NA | NA | NA | NA | NA
channel 4 | OFF | OFF | OFF | OFF | OFF | NA | NA | NA | NA | NA | NA | NA | NA | NA | NA
channel 5 | OFF | OFF | OFF | OFF | OFF | NA | NA | NA | NA | NA | NA | NA | NA | NA | NA
channel 6 | OFF | OFF | OFF | OFF | OFF | NA | NA | NA | NA | NA | NA | NA | NA | NA | NA
channel 7 | OFF | OFF | OFF | OFF | OFF | NA | NA | NA | NA | NA | NA | NA | NA | NA | NA
channel 8 | OFF | OFF | OFF | OFF | OFF | NA | NA | NA | NA | NA | NA | NA | NA | NA | NA
SCHEME 6 | DON'T USE |  |  |  | TITLE: | no title
 | Pos 1 | Pos 2 | Pos 3 | Pos 4 | Pos 5 | Forward | Reverse | Stop | StopDelay | Brake | Right Turn | Left Turn | No Turn | Accelerating | Decelerating
channel 1 | OFF | OFF | OFF | OFF | OFF | NA | NA | NA | NA | NA | NA | NA | NA | NA | NA
channel 2 | OFF | OFF | OFF | OFF | OFF | NA | NA | NA | NA | NA | NA | NA | NA | NA | NA
channel 3 | OFF | OFF | OFF | OFF | OFF | NA | NA | NA | NA | NA | NA | NA | NA | NA | NA
channel 4 | OFF | OFF | OFF | OFF | OFF | NA | NA | NA | NA | NA | NA | NA | NA | NA | NA
channel 5 | OFF | OFF | OFF | OFF | OFF | NA | NA | NA | NA | NA | NA | NA | NA | NA | NA
channel 6 | OFF | OFF | OFF | OFF | OFF | NA | NA | NA | NA | NA | NA | NA | NA | NA | NA
channel 7 | OFF | OFF | OFF | OFF | OFF | NA | NA | NA | NA | NA | NA | NA | NA | NA | NA
channel 8 | OFF | OFF | OFF | OFF | OFF | NA | NA | NA | NA | NA | NA | NA | NA | NA | NA
SCHEME 7 | DON'T USE |  |  |  | TITLE: | no title
 | Pos 1 | Pos 2 | Pos 3 | Pos 4 | Pos 5 | Forward | Reverse | Stop | StopDelay | Brake | Right Turn | Left Turn | No Turn | Accelerating | Decelerating
channel 1 | OFF | OFF | OFF | OFF | OFF | NA | NA | NA | NA | NA | NA | NA | NA | NA | NA
channel 2 | OFF | OFF | OFF | OFF | OFF | NA | NA | NA | NA | NA | NA | NA | NA | NA | NA
channel 3 | OFF | OFF | OFF | OFF | OFF | NA | NA | NA | NA | NA | NA | NA | NA | NA | NA
channel 4 | OFF | OFF | OFF | OFF | OFF | NA | NA | NA | NA | NA | NA | NA | NA | NA | NA
channel 5 | OFF | OFF | OFF | OFF | OFF | NA | NA | NA | NA | NA | NA | NA | NA | NA | NA
channel 6 | OFF | OFF | OFF | OFF | OFF | NA | NA | NA | NA | NA | NA | NA | NA | NA | NA
channel 7 | OFF | OFF | OFF | OFF | OFF | NA | NA | NA | NA | NA | NA | NA | NA | NA | NA
channel 8 | OFF | OFF | OFF | OFF | OFF | NA | NA | NA | NA | NA | NA | NA | NA | NA | NA
SCHEME 8 | DON'T USE |  |  |  | TITLE: | no title
 | Pos 1 | Pos 2 | Pos 3 | Pos 4 | Pos 5 | Forward | Reverse | Stop | StopDelay | Brake | Right Turn | Left Turn | No Turn | Accelerating | Decelerating
channel 1 | OFF | OFF | OFF | OFF | OFF | NA | NA | NA | NA | NA | NA | NA | NA | NA | NA
channel 2 | OFF | OFF | OFF | OFF | OFF | NA | NA | NA | NA | NA | NA | NA | NA | NA | NA
channel 3 | OFF | OFF | OFF | OFF | OFF | NA | NA | NA | NA | NA | NA | NA | NA | NA | NA
channel 4 | OFF | OFF | OFF | OFF | OFF | NA | NA | NA | NA | NA | NA | NA | NA | NA | NA
channel 5 | OFF | OFF | OFF | OFF | OFF | NA | NA | NA | NA | NA | NA | NA | NA | NA | NA
channel 6 | OFF | OFF | OFF | OFF | OFF | NA | NA | NA | NA | NA | NA | NA | NA | NA | NA
channel 7 | OFF | OFF | OFF | OFF | OFF | NA | NA | NA | NA | NA | NA | NA | NA | NA | NA
channel 8 | OFF | OFF | OFF | OFF | OFF | NA | NA | NA | NA | NA | NA | NA | NA | NA | NA
SCHEME 9 | DON'T USE |  |  |  | TITLE: | no title
 | Pos 1 | Pos 2 | Pos 3 | Pos 4 | Pos 5 | Forward | Reverse | Stop | StopDelay | Brake | Right Turn | Left Turn | No Turn | Accelerating | Decelerating
channel 1 | OFF | OFF | OFF | OFF | OFF | NA | NA | NA | NA | NA | NA | NA | NA | NA | NA
channel 2 | OFF | OFF | OFF | OFF | OFF | NA | NA | NA | NA | NA | NA | NA | NA | NA | NA
channel 3 | OFF | OFF | OFF | OFF | OFF | NA | NA | NA | NA | NA | NA | NA | NA | NA | NA
channel 4 | OFF | OFF | OFF | OFF | OFF | NA | NA | NA | NA | NA | NA | NA | NA | NA | NA
channel 5 | OFF | OFF | OFF | OFF | OFF | NA | NA | NA | NA | NA | NA | NA | NA | NA | NA
channel 6 | OFF | OFF | OFF | OFF | OFF | NA | NA | NA | NA | NA | NA | NA | NA | NA | NA
channel 7 | OFF | OFF | OFF | OFF | OFF | NA | NA | NA | NA | NA | NA | NA | NA | NA | NA
channel 8 | OFF | OFF | OFF | OFF | OFF | NA | NA | NA | NA | NA | NA | NA | NA | NA | NA
SCHEME 10 | DON'T USE |  |  |  | TITLE: | no title
 | Pos 1 | Pos 2 | Pos 3 | Pos 4 | Pos 5 | Forward | Reverse | Stop | StopDelay | Brake | Right Turn | Left Turn | No Turn | Accelerating | Decelerating
channel 1 | OFF | OFF | OFF | OFF | OFF | NA | NA | NA | NA | NA | NA | NA | NA | NA | NA
channel 2 | OFF | OFF | OFF | OFF | OFF | NA | NA | NA | NA | NA | NA | NA | NA | NA | NA
channel 3 | OFF | OFF | OFF | OFF | OFF | NA | NA | NA | NA | NA | NA | NA | NA | NA | NA
channel 4 | OFF | OFF | OFF | OFF | OFF | NA | NA | NA | NA | NA | NA | NA | NA | NA | NA
channel 5 | OFF | OFF | OFF | OFF | OFF | NA | NA | NA | NA | NA | NA | NA | NA | NA | NA
channel 6 | OFF | OFF | OFF | OFF | OFF | NA | NA | NA | NA | NA | NA | NA | NA | NA | NA
channel 7 | OFF | OFF | OFF | OFF | OFF | NA | NA | NA | NA | NA | NA | NA | NA | NA | NA
channel 8 | OFF | OFF | OFF | OFF | OFF | NA | NA | NA | NA | NA | NA | NA | NA | NA | NA

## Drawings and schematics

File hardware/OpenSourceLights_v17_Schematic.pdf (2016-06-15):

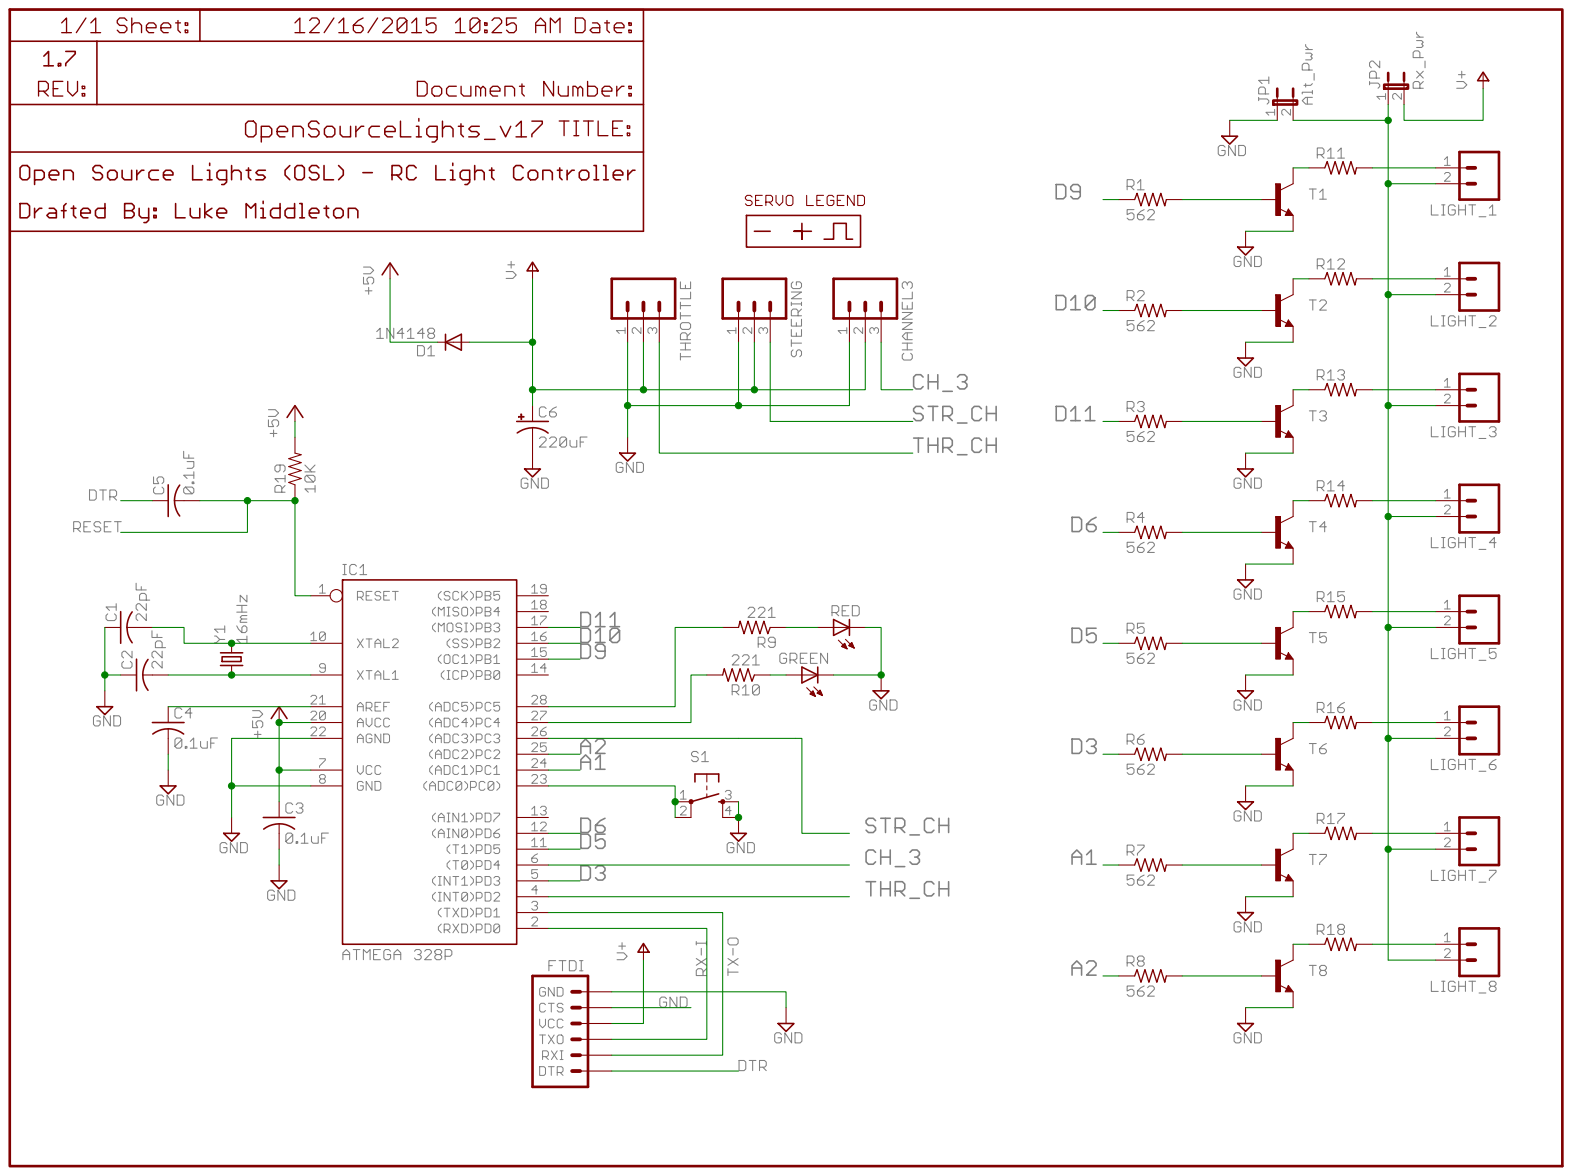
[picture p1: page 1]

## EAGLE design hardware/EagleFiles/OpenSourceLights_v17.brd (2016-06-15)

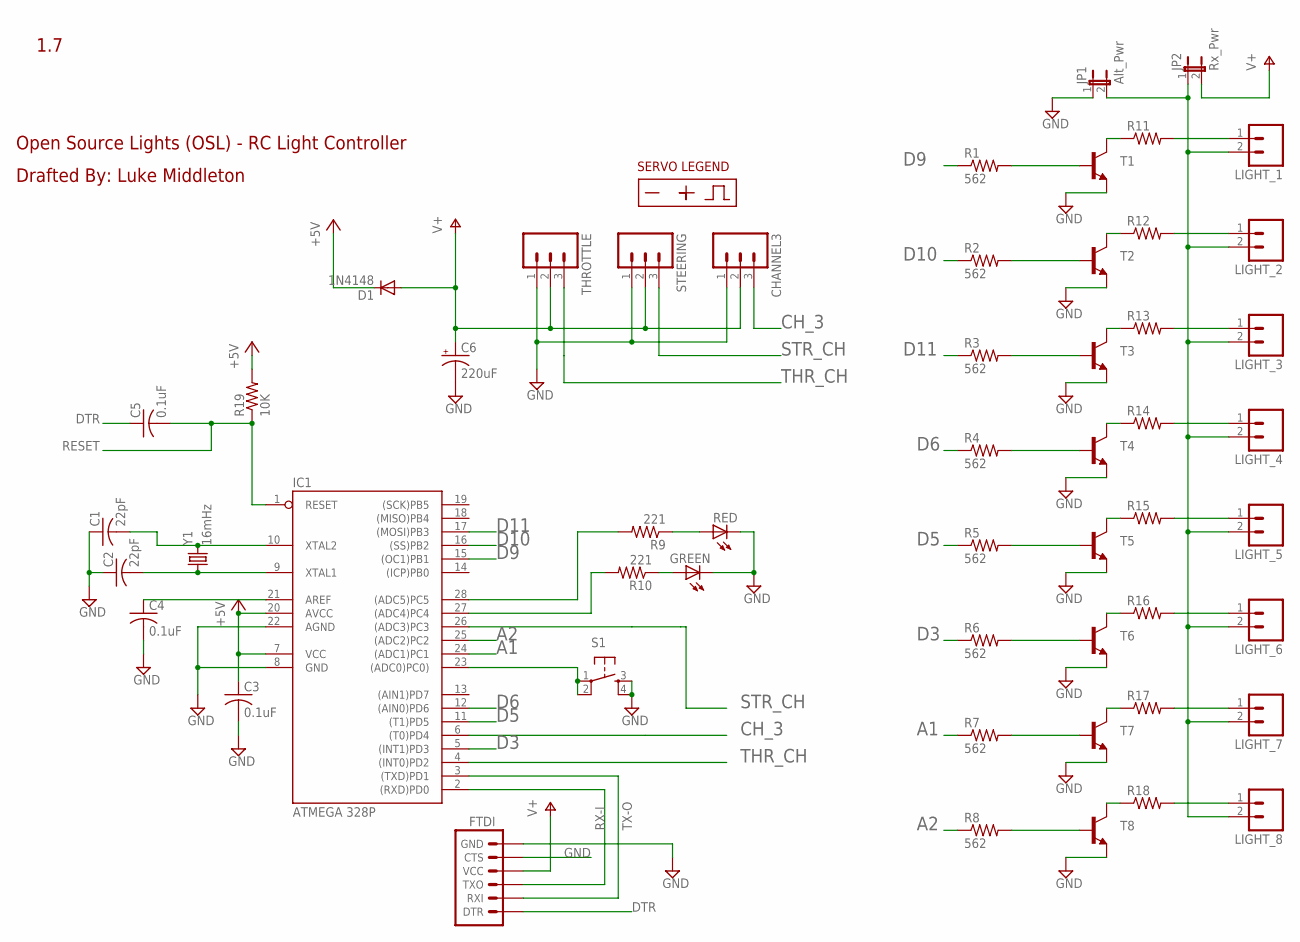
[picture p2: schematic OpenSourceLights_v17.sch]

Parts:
C1, C2: 22pF; C025-025X050
C3, C4, C5: 0.1uF; C025-025X050
C6: 220uF; E5-10,5
CHANNEL3: M03LOCK; 1X03_LOCK
D1: 1N4148; DO35-10
FTDI: ARDUINO_SERIAL_PROGRAMLOCK; 1X06_LOCK
GREEN: LED3MM
IC1: ATMEGA 328P; DIL28-3
JP1: Alt_Pwr; 1X02
JP2: Rx_Pwr; SJ_2S-NO
LIGHT_1, LIGHT_2, LIGHT_3, LIGHT_4, LIGHT_5, LIGHT_6, LIGHT_7, LIGHT_8: M02JST-PTH-2_LARGEDRILL; JST-2-PTH+
R1, R2, R3, R4, R5, R6, R7, R8: 562; RESISTOR_VERTICAL
R9, R10: 221; RESISTOR_VERTICAL
R11, R12, R13, R14, R15, R16, R17, R18: RESISTOR; RESISTOR_VERTICAL
R19: 10K; AXIAL-0.4
RED: LED3MM
S1: TAC_SWITCHPTH; TACTILE-PTH
STEERING: M03LOCK; 1X03_LOCK
T1, T2, T3, T4, T5, T6, T7, T8: TRANSISTOR_NPNTH; TO92
THROTTLE: M03LOCK; 1X03_LOCK
U$1: SYMBOLS_SERVONEG_POS_SIG; SYMBOLS_SERVO_REVERSE
Y1: 16mHz; HC49US

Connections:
+5V: C3.1, D1.C, IC1.7 (VCC), IC1.20 (AVCC), R19.P$2 (2)
A1: IC1.24 ((ADC1)PC1), R7.1
A2: IC1.25 ((ADC2)PC2), R8.1
ALTPWR: JP1.2, JP2.1, LIGHT_1.2, LIGHT_2.2, LIGHT_3.2, LIGHT_4.2, LIGHT_5.2, LIGHT_6.2, LIGHT_7.2, LIGHT_8.2
CH_3: CHANNEL3.3, IC1.6 ((T0)PD4)
D3: IC1.5 ((INT1)PD3), R6.1
D5: IC1.11 ((T1)PD5), R5.1
D6: IC1.12 ((AIN0)PD6), R4.1
D9: IC1.15 ((OC1)PB1), R1.1
D10: IC1.16 ((SS)PB2), R2.1
D11: IC1.17 ((MOSI)PB3), R3.1
DTR: C5.1, FTDI.1 (DTR)
GND: C1.1, C2.1, C3.2, C4.2, C6.-, CHANNEL3.1, FTDI.5 (CTS), FTDI.6 (GND), GREEN.K (C), IC1.8 (GND), IC1.22 (AGND), JP1.1, RED.K (C), S1.3, S1.4, STEERING.1, T1.3 (E), T2.3 (E), T3.3 (E), T4.3 (E), T5.3 (E), T6.3 (E), T7.3 (E), T8.3 (E), THROTTLE.1
unnamed: LIGHT_1.1, R11.2
unnamed: LIGHT_2.1, R12.2
unnamed: LIGHT_3.1, R13.2
unnamed: LIGHT_4.1, R14.2
unnamed: LIGHT_5.1, R15.2
unnamed: LIGHT_6.1, R16.2
unnamed: LIGHT_7.1, R17.2
unnamed: LIGHT_8.1, R18.2
unnamed: C1.2, IC1.10 (XTAL2), Y1.2
unnamed: R1.2, T1.2 (B)
unnamed: R2.2, T2.2 (B)
unnamed: R3.2, T3.2 (B)
unnamed: R4.2, T4.2 (B)
unnamed: R5.2, T5.2 (B)
unnamed: R6.2, T6.2 (B)
unnamed: R7.2, T7.2 (B)
unnamed: R8.2, T8.2 (B)
unnamed: C2.2, IC1.9 (XTAL1), Y1.1
unnamed: R11.1, T1.1 (C)
unnamed: R12.1, T2.1 (C)
unnamed: C4.1, IC1.21 (AREF)
unnamed: R13.1, T3.1 (C)
unnamed: R14.1, T4.1 (C)
unnamed: R15.1, T5.1 (C)
unnamed: R16.1, T6.1 (C)
unnamed: R17.1, T7.1 (C)
unnamed: R18.1, T8.1 (C)
unnamed: GREEN.A, R10.1
unnamed: IC1.23 ((ADC0)PC0)), S1.1, S1.2
unnamed: R9.1, RED.A
unnamed: IC1.27 ((ADC4)PC4), R10.2
unnamed: IC1.28 ((ADC5)PC5), R9.2
RESET: C5.2, IC1.1 (RESET), R19.P$1 (1)
RX-I: FTDI.3 (TXO), IC1.2 ((RXD)PD0)
STR_CH: IC1.26 ((ADC3)PC3), STEERING.3
THR_CH: IC1.4 ((INT0)PD2), THROTTLE.3
TX-O: FTDI.2 (RXI), IC1.3 ((TXD)PD1)
V+: C6.+, CHANNEL3.2, D1.A, FTDI.4 (VCC), JP2.2, STEERING.2, THROTTLE.2

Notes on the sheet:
1.7
Drafted By: Luke Middleton
Open Source Lights (OSL) - RC Light Controller

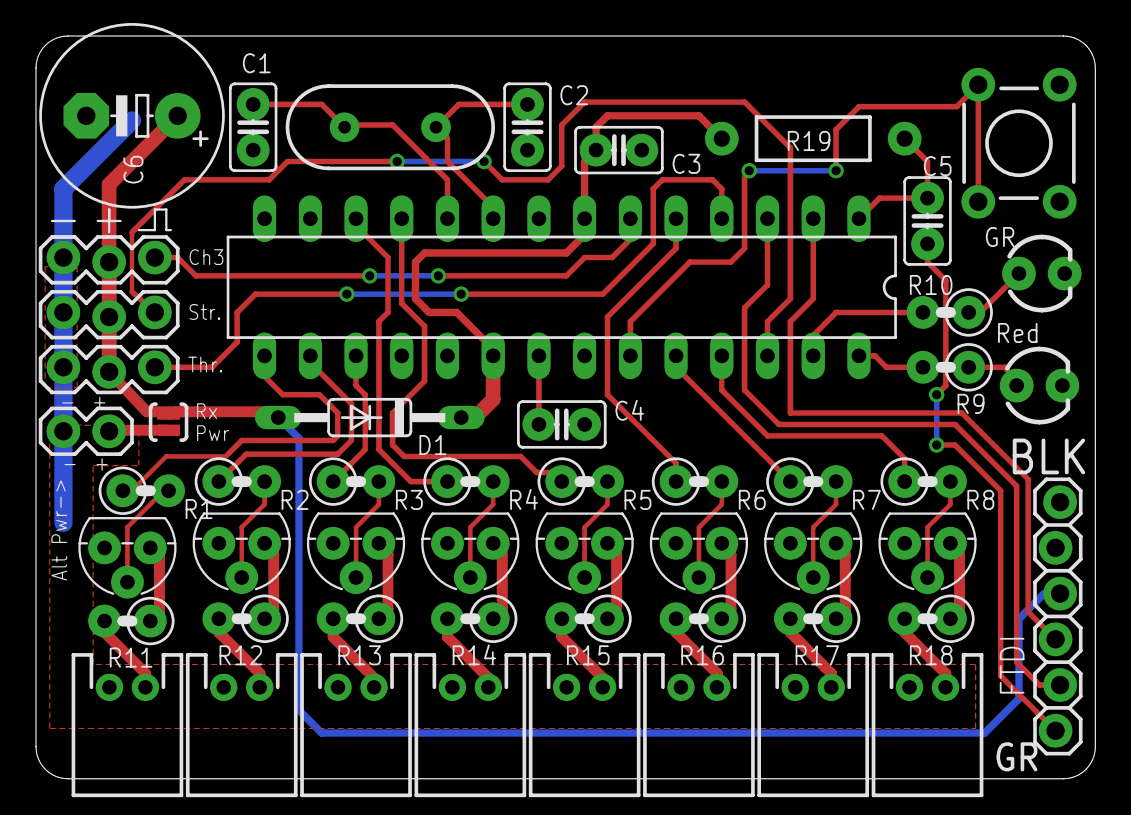
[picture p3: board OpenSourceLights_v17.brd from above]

Board: 2 copper layers, 58.9 x 41.3 mm, 55 parts (1 on the bottom side), 51 nets.

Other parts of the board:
U$2: SYMBOLS_SERVONEG_POS_SIG; SYMBOLS_SERVO_REVERSE

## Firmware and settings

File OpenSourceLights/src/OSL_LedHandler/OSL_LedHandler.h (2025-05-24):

/* OSL_LedHandler.h     Led Handler - class for handling LEDs, requires use of elapsedMillis
 * Source:              https://github.com/OSRCL
 * Authors:             Luke Middleton
 *   
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
 */  

#ifndef OSL_LedHandler_h
#define OSL_LedHandler_h

#include <Arduino.h>
#include "../elapsedMillis/elapsedMillis.h"
#include "../../AA_UserConfig.h"


// These are all the possible states the light can be in, within this class. These are not always strictly the same thing as the states within the sketch,
// and an output may go though multiple states to get to the state the sketch wants (transition states)
#define LED_STATE_OFF					      0	
#define LED_STATE_ON					      1	
#define LED_STATE_DIM					      2	
#define LED_STATE_BLINK				   	      3				// Applies to both Blink and FastBlink
#define LED_STATE_SOFTBLINK			          4	
#define LED_STATE_RANDOMBLINK			      5	
#define LED_STATE_FADE				   	      6	
#define LED_STATE_XENON				          7	
#define LED_STATE_FADE_TO				      8	
#define LED_STATE_SAFETYBLINK				  9

// Stream blinker struct
#define MAX_STREAM_STEPS                    10            	// A stream consists of a pattern of on/off blinks separated by user-specified lengths of time. A single blink (on/off) takes 2 steps. 
typedef struct                                          	// This struct holds an array of blink patterns, and a flag to indicate if it should repeat or not
{
    uint16_t        interval[MAX_STREAM_STEPS];
    boolean         repeat;
	boolean			altBlink;
} BlinkStream;

#define DEFAULT_BLINK_INTERVAL              378				// Used when an interval is not specified, though OSL always will

#define MIN_PWM							      0				// PWM value at Off
#define MIN_PWM_FLOAT					    0.0
#define MAX_PWM							    255				// PWM value at On
#define MAX_PWM_FLOAT				      255.0	

// Fading - You really probably shouldn't change any of this! These are the settings that work best with the hardcoded processes in the cpp file. 
#define FADE_IN                               1
#define FADE_OUT                              2
#define FADE_TYPE_EXP				          0				// There are two types of fades, but for purposes of RC cars exponential looks better (and sometimes we modify even that)
#define FADE_TYPE_SINE					      1				// I don't believe we end up using the sine fade anywhere
															// For exponential fades the formula for fade-outs (decrease brightness) is pwm = priorPWM * Ratio. 
															// For fade-ins (increase brightness) the formula is pwm = priorPWM + ((1-Ratio) * priorPWM)
#define SINE_START_ANGLE_ON			       1.57				// Sine fading is more complicated and involves using angular math, these are the angles on a sine wave
#define SINE_START_ANGLE_OFF		      4.712				// that represent the peak of the curve (on) or the trough (off)
#define NUM_FADE_UPDATES                     50				// Used for fading in or out from full on or off
#define DEFAULT_FADE_TIME				    500				// Length of time for generic fade
#define FADE_OFF_RATIO					    0.9				// We decrease the PWM by this ratio each step of a standard fade
#define FADE_ON_R_VAL				    12.5088				// Used for exponential fade-ins
#define FADE_TO_RATIO			            0.9				// We can have a different fade-out ratio for the fade-to function (fades to a target, rather than full off)

#define XENON_STEP_1_ON_TIME     		     50				// Step 1 in the xenon process - how long to flash the LED at full brightness to start 
#define XENON_STEP_2_DIM_TIME			    100		    	// Step 2 in the xenon process - how long to turn off the light, or set it very dim, after the first flash
#define XENON_STEP_2_DIM_LEVEL			      0				// Step 2 in the xenon process - how bright during this brief interval between the flash and fade in. Set to 0 to keep it off
#define XENON_STEP_3_FADE_TIME			   6000				// Step 3 in the xenon process - how long should the fade-in take. Sergio Pizzotti's original implementation was about 6.3 seconds with the initial flash. 
#define XENON_STEP_3_FADE_STEPS		        150				// Step 3 in the xenon process - how many steps for the fade in. All these numbers work together, and with the actual code in .cpp, so if you change anything, 
															// you will need to change the code as well. See the Excel spreadsheet for what they represent. Best to just leave everything alone. 
											
#define SOFTBLINK_STEP_1_FADE_ON_TIME  	    220		    	// Step 1 in the soft blink process - how long does the initial fade-in take
#define SOFTBLINK_STEP_1_FADE_ON_STEPS	     20	
#define SOFTBLINK_STEP_2_ON_TIME		    100				// Step 2 in the soft blink process - how long to remain at full brightness
#define SOFTBLINK_STEP_3_FADE_OFF_TIME	    416		    	// Step 3 in the soft blink process - how long does the fade-out take
#define SOFTBLINK_STEP_3_FADE_OFF_STEPS      32	
#define SOFTBLINK_FADE_ON_RATIO			   0.24			
#define SOFTBLINK_FADE_OFF_RATIO		   0.84	
#define SOFTBLINK_TO_TARGET_FADEDOWN_ONLY false				// This is one of the few defines you can change without messing anything up. If set to true, when a softblink ends and the next state is dim, 
															// this will cause the blink to stop at the dim level only when fading down. That means if the change to dim occurs when the softblink effect is lower
															// than the desired dim level, the softblink will blink one more time to full brightness and then stop at dim on the way down. 
															// If set to false, it will stop at the desired dim level on either the upswing or down, depending on which happens first. 
															// I think the stop on fadedown only looks better, but you may end up with one extra blink at stop, so if you don't like that set the define to false. 
class OSL_LedHandler
{   public:
        OSL_LedHandler() {}; 
        
        void begin (byte p, boolean i=false, boolean w=false); 					// p = pin, i = invert, w = pwm-able
        void on(void);
		boolean isOn(void);
        void off(void);
        void toggle(void);
		void dim(uint8_t level);												// Level should be between 0-MAX_PWM
        void update(void);                                                      // Update blinking effect
        void Blink(uint16_t interval=DEFAULT_BLINK_INTERVAL);                   // Blinks once at interval specified
        void Blink(uint8_t times, uint16_t interval=DEFAULT_BLINK_INTERVAL);    // Overload - Blinks N times at interval specified (on and off interval will be the same)
		void Blink(uint8_t times, uint16_t on_interval=DEFAULT_BLINK_INTERVAL, uint16_t off_interval=DEFAULT_BLINK_INTERVAL);   // Overload - Blinks N times at intervals specified (on and off time individually set)
        void startBlinking(uint16_t on_interval=DEFAULT_BLINK_INTERVAL, uint16_t off_interval=DEFAULT_BLINK_INTERVAL, boolean alt=false);   // Starts a continuous blink at the set intervals
		void stopBlinking(void);
		void softBlink(void);
        void StreamBlink(BlinkStream bs, uint8_t numSteps);
		void randomBlink(void);
        void Fade(uint8_t fade_in, uint16_t span, char f=FADE_TYPE_EXP);
		void FadeTo(uint8_t desiredLevel);
        void stopFading(void);		
		void Xenon(void);
		void SafetyBlink(uint16_t sbRate, uint8_t sbCount, uint16_t sbInt, boolean alt=false);	
        
		
    private:
		void clearUpdateProcess(void);
        void pinOn(void);
        void pinOff(void);
		void offWithExtra(boolean includeExtra=false);
		void setPWM(float level);
		void changeLEDState(uint8_t changeState);
		void softBlinkWithStartFlag(boolean start=false);
        elapsedMillis   _time;
        byte            _pin;
		boolean			_pwmable;
		float			_pwm;
		boolean			_fadeToTarget; 
		int16_t			_pwmTarget;
        boolean         _invert;
		uint8_t			_fadeType;
		uint8_t         _fadeDirection;		
		uint8_t			_curProcessStep;
		uint8_t			_numProcessSteps;
		boolean		    _AltProcess;
        uint8_t         _curStep;
		uint8_t         _numSteps;
        uint16_t        _nextWait;
        boolean         _fixedInterval;
        BlinkStream     _blinkStream;
		boolean			_blinkToDim;
        float           _fadeAdjustment;
		uint8_t			_ledCurState;
		uint8_t			_ledPriorState;
		uint16_t		_safetyBlinkRate;
		uint8_t			_safetyBlinkCount;
		uint16_t		_safetyBlinkInterval;
		uint16_t		_safetyBlinkCountTimesTwo;
};


#endif 

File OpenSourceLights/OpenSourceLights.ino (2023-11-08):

 /*
 * Open Source Lights   An Arduino-based program to control LED lights on RC vehicles. 
 * Copyright 2011       Luke Middleton
 *
 * For more information, see the RCGroups thread: 
 * http://www.rcgroups.com/forums/showthread.php?t=1539753
 * 
 * GitHub Repository:
 * https://github.com/OSRCL/OSL_Original
 * 
 *
 * To compile select               Tools -> Board     -> Arduino Duemilanove or Diecimila or Nano
 * Also select correct processor   Tools -> Processor -> ATmega328P
 *                                 If you have problems writing to the device, try Tools -> Processor -> Atmega328P (Old Bootloader)
 *
*/

// ====================================================================================================================================================>
//  INCLUDES 
// ====================================================================================================================================================>
    #include "AA_UserConfig.h"
    #include "src/OSL_Settings/OSL_Settings.h"
    #include "src/elapsedMillis/elapsedMillis.h"
    #include "src/OSL_Button/OSL_Button.h"  // By JChristensen. See: https://github.com/JChristensen/Button Renamed from Button to OSL_Button so it won't conflict with other button libraries. 
    #include "src/OSL_LedHandler/OSL_LedHandler.h"
    #include "src/OSL_SimpleTimer/OSL_SimpleTimer.h"
    #include "src/OSL_PinChangeInterrupt/PinChangeInterrupt.h"

   
// ====================================================================================================================================================>
//  GLOBAL VARIABLES
// ====================================================================================================================================================>

    // Hardware version
    // -------------------------------------------------------------------------------------------------------------------------------------------------->                
        uint8_t HardwareVersion =             1;                // We will detect the actual hardware version later in Setup, this just initializes to something.

    // Startup
    // ------------------------------------------------------------------------------------------------------------------------------------------------>
        boolean Startup                  = true;                // This lets us run a few things in the main loop only once instead of over and over

    // Objects
    // -------------------------------------------------------------------------------------------------------------------------------------------------->            
        OSL_LedHandler                   RedLED;
        OSL_LedHandler                 GreenLED;
        OSL_LedHandler   LightOutput[NumLights];                // LED handler for each output (NUM_LIGHT_OUTPUTS is defined in OSL_Settings.h)
        OSL_Button                  InputButton;                // Button object, will get set later in Setup() when we know what hardware version we are running on.

    // Simple Timer
    // ------------------------------------------------------------------------------------------------------------------------------------------------>
        OSL_SimpleTimer                   timer;                // Instantiate a SimpleTimer named "timer"
        boolean TimeUp                   = true;

    // EEPROM
    // ------------------------------------------------------------------------------------------------------------------------------------------------>
        const long EEPROM_Init         = 0xDF03;                // Change this any time the EEPROM content changes
        struct __eeprom_data {                                  // __eeprom_data is the structure that maps all of the data we are storing in EEPROM
          long E_InitNum;                                       // Number that indicates if EEPROM values have ever been initialized 
          int16_t E_ThrottlePulseMin;
          int16_t E_ThrottlePulseMax;
          int16_t E_ThrottlePulseCenter;
          int16_t E_TurnPulseMin;
          int16_t E_TurnPulseMax;
          int16_t E_TurnPulseCenter;
          int16_t E_Channel3PulseMin;
          int16_t E_Channel3PulseMax;
          int16_t E_Channel3PulseCenter;
          boolean E_ThrottleChannelReverse;
          boolean E_TurnChannelReverse;
          boolean E_Channel3Reverse;
          uint8_t E_CurrentScheme;
        };

    // RC Channel defines
    // -------------------------------------------------------------------------------------------------------------------------------------------------->            
        struct _rc_channel {
            uint8_t  pin;                                       // Pin number of channel
            uint8_t  channel;                                   // What channel is this (0 = throttle, 1 = steering, 2 = Channel 3)
            char     state;                                     // State of this individual channel (acquiring, synched, lost)
            uint16_t rawPulseWidth;                             // Unchecked pulse-width, may or may not be valid
            int16_t  pulse;                                     // Actual pulse-width in uS, typically in the range of 1000-2000 (sanity checked). Although it should always be positive, this needs to be signed for smoothing to work.
            int16_t  pulseMin;                                  // Minimum pulse width of incoming channel, as saved during Radio Setup
            int16_t  pulseCenter;                               // Center pulse width of incoming channel, as saved during Radio Setup
            int16_t  pulseMax;                                  // Maximum pulse width of incoming channel, as saved during Radio Setup
            uint8_t  deadband;                                  // Deadband around center where changes are ignored
            boolean  readyForUpdate;                            // Set to true if a signal has been read (saved to rawPulseWidth) and we are ready for the main loop to process
            boolean  updated;                                   // Has the value on this channel changed since the last check?
            boolean  reversed;                                  // Should this channel be reversed
            int8_t   mappedCommand;                             // For throttle and steering channels, the current command (adjusted for known center and endpoint settings, and mapped to a range of -100 to 100)
            uint8_t  numSwitchPos;                              // In the case of a digital channel, how many switch positions can it read. 
            uint8_t  switchPos;                                 // In the case of Channel 3, what switch "position" is the channel presently in
            boolean  smooth;                                    // Apply averaging to the incoming value
            int16_t  smoothedValue;                             // Remember the last value to use for smoothing (we smooth the pulse, not the mapped command/switch position, so values are always positive)
            uint32_t lastEdgeTime;                              // Timing variable for measuring pulse width
            uint32_t lastGoodPulseTime;                         // Time last signal was received for this channel
            uint8_t  acquireCount;                              // How many pulses have been acquired during acquire state
            boolean  Digital;                                   // Is this a digital channel (switch input) or an analog (variable) input?             
        }; 
        _rc_channel RC_Channel[NUM_RC_CHANNELS];

        boolean Failsafe                = false;                // If we loose contact with the Rx this flag becomes true
        char RC_State =  RC_SIGNAL_UNINITIALIZED;               // State of the entire radio system (as opposed to per-channel states above)
        char Last_RC_State = RC_SIGNAL_UNINITIALIZED;           // Last state. The uninitialized state is used only once, at startup, afterwards it is either acquiring, synched, or lost
        int RxSignalLostTimerID             = 0;                // Timer used to flash the lights if the radio signal is lost
        int8_t ThrottleCommand              = 0;                // Discrete variables are also useful, we will map these to the correct channel inputs in ProcessRCCommand()
        int8_t TurnCommand                  = 0;
        uint8_t Channel3Command             = 0;                        
        int8_t ThrottleCommand_Previous     = 0;                // We keep a second set so we can compare and determine when a command has changed
        uint8_t Channel3Command_Previous    = 0;
        int8_t TurnCommand_Previous         = 0;

    // Driving
    // ------------------------------------------------------------------------------------------------------------------------------------------------>
        boolean Braking                 = false;                // Are we braking       
        boolean Braking_Previous        = false;                // Allows us to track changes     
        boolean Decelerating            = false;                // Are we sharply decelerating 
        boolean Accelerating             = true;                // Are we sharply accelerating
        boolean StoppedLongTime         = false;                // Have we been stopped for a long time (actual length of time set on the AA_UserConfig tab - LongStopTime_mS)
        int8_t Direction              = NO_TURN;                // As opposed to command which indicates how much we are turning, this just tells us if we are in a right turn, left turn, or no turn.
        int8_t Direction_Previous     = NO_TURN;
        boolean TurnSignal_Enable       =  true;                // If the user decides to restrict turn signals only to when the car is stopped, they can further add a delay that begins
                                                                // when the car first stops, and until this delay is complete, the turn signals won't come on. This flag indicates if the delay
                                                                // is up. Initialize to true, otherwise turn signals won't work until the car has driven forward once and stopped.
        int8_t TurnSignalOverride           = 0;                // The other situation we want to modify the turn signal is when starting from a stop, while turning. In this case we leave the turn signals on
                                                                // for a period of time even after the car has started moving (typically turn signals are disabled while moving). This mimics a real car where
                                                                // the turn signal isn't cancelled until after the steering wheel turns back the opposite way. In our case we don't check the steering wheel, 
                                                                // we just wait a short amount of time (user configurable in AA_UserConfig.h, variable TurnFromStartContinue_mS)
    // Light Settings
    // ------------------------------------------------------------------------------------------------------------------------------------------------>
        uint8_t LightSettings[NumLights][NumStates];            // An array to hold the settings for each state for each light. 
        uint8_t CurrentLightSetting[NumLights];                 // What state is the light in presently
        boolean canBackfire             = false;                // Is the backfiring effect currently active?
        uint16_t backfire_timeout;                              // Will save the random timeout interval to turn off the LED
        int BackfireTimerID                 = 0;                // Backfire event timer ID
        boolean Overtaking              = false;                // Overtaking effect
        int OvertakeTimerID                 = 0;                // Overtaking event timer ID
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
void loop()
{
    // Main loop local variables
    // ------------------------------------------------------------------------------------------------------------------------------------------------>    
    // Drive Modes
    static uint8_t DriveModeCommand      = STOP;                // The Drive Mode presently being commanded by user. At startup we don't know, so initialize to UNKNOWN.
    static uint8_t DriveMode             = STOP;                // As opposed to DriveModeCommand, this is the actual DriveMode being implemented. 
    static uint8_t DriveMode_Previous    = STOP;                // The previous Drive Mode implemented. There is no "previous" when first started, initialize to STOP
    static uint8_t DriveModeCommand_Previous = STOP;            // There is no "previous" command when we first start. Initialize to STOP
    static uint8_t DriveMode_LastDirection = STOP;


    // Driving
    static boolean canBrake             = false;                // If BrakeAtThrottlePctBelow > 0 (in AA_UserConfig) we may set the brake flag even when moving in forward or reverse
    static uint32_t TimeStopped;                                // When did we stop - will be used to initiate a delay after stopping before turn signals can be used, or when stop-delay light settings can take effect.
    static uint32_t StopCMDLength;                              // Counter to determine how long we have been commanding Stop.
    static uint32_t Last_FWD_Time;                              // Keep track of how recently we were in forward. This will help us know whether to enter the Brake state or not. NOTE: The brake state
                                                                // will only ever apply if DoubeTapReverse = true. For crawler type ESCs that can go directly into reverse from forward, the only way to get
                                                                // the brake lights to turn on is to set them to the Stop state. 
    static uint8_t ReverseTaps              = 0;                // How many times have we gone into reverse - used for ESCs that require tapping reverse twice before the car will move in reverse


    // Scheme change variables
    #define CSM_StopDelay_mS               3000L                // How long after being stopped should we wait before we enable the user to enter change-scheme-mode
    #define CS_MAX_TURN                       90                // 90 percent of Turn Command, we consider this a full turn for purposes of the change-scheme selection
    #define CS_MIN_TURN                       20                // 20 percent of Turn Command, this is the minimum movement to be considered a turn command during Change-Scheme-Mode
    static byte RightCount                  = 0;                // We use these to count up the number of times the user has cranked the
    static byte LeftCount                   = 0;                // steering wheel completely over. 
    #define ChangeModeTime_mS              2000L                // Amount of time user has to enter Change-Scheme-Mode (this is the time within which they must turn the wheel back and forth rapidly)
    static boolean ChangeSchemeTimerFlag = false;               // Has the timer begun
    static int CSM_TurnTimerID;                                 // An ID for the timer that counts the turns of the wheel                      
    static int8_t ExitSchemeFlag            = 0;                // A flag to indicate whether or not to exit Change-Scheme-Mode
    #define CSM_ChangeTime_mS                400                // How long to hold the wheel over to increment/decrement to the next scheme
    #define CSM_TimeToWait_mS              1200L                // Time to wait between change-scheme commands (otherwise as long as you held the wheel over it would keep cycling through rapidly)
    #define CSM_TimeToExit_mS              3000L                // How long to hold the wheel over until Change-Scheme-Mode is exited
    static unsigned long CSM_ExitStart;                         // Start time of the exit waiting period
    #define CSM_InactiveExit_Time         20000L                // If there are no commands given for this length of time, automatically exit change-scheme-mode
    static boolean TimeoutFlag;
    static boolean HoldFlag; 
    static unsigned long HoldStart;
    static uint32_t TransitionStart;


    // Temp vars
    static unsigned long currentMillis;        
    static boolean WhatState = true;
   

    // STARTUP - RUN ONCE
    // ------------------------------------------------------------------------------------------------------------------------------------------------>    
    if (Startup)
    {       
        RedLED.off();                                           // Start with these off
        GreenLED.off();

        if (enableShelfQueenMode)
        {
            uint8_t tempScheme; 
            shelfQueenMode = true;                              // Set this to true temporarily, we need to do this prior to actually entering shelf-queen mode to prevent the radio failsafe handler from messing things up
            delayWhilePolling(100);                             // Let's give ourselves plenty of time to detect something

            if (RC_State == RC_SIGNAL_UNINITIALIZED)
            {
                // Change the scheme to the shelf-queen scheme
                if (shelfQueenSchemeNumber > NumSchemes) tempScheme = 1; // If the user has entered an invalid scheme number, default to 1
                else                                     tempScheme = shelfQueenSchemeNumber;

                if (enableShelfQueenDelay)
                {
                    // We want to delay some random amount of time before turning the lights on
                    uint32_t sq_delay; 
                    sq_delay = random(sqd_Time_Short, sqd_Time_Long);
                    Serial.print(F("Shelf Queen Mode Delay: ")); Serial.print(((float)sq_delay/1000.0),1); Serial.println(F(" seconds"));
                    
                    currentMillis = millis();                   // Save the time
                    do {
                        PerLoopUpdates();
                    } while (((millis() - currentMillis) < sq_delay) && RC_State == RC_SIGNAL_UNINITIALIZED); 
                }

                if (RC_State != RC_SIGNAL_UNINITIALIZED)
                {
                    // The radio was detected while we were waiting, cancel shelf queen mode
                    shelfQueenMode = false; 
                }
    
                if (shelfQueenMode == true)
                {
                    // Ok, we're still good to enter shelf queen mode
                    if (DEBUG)
                    {
                        Serial.println();
                        Serial.println();
                        PrintLine(80);
                        Serial.print(F("SHELF QUEEN MODE - SCHEME ")); Serial.println(tempScheme);
                        PrintLine(80);
                    }
    
                    // Load the desired scheme
                    SetLightScheme(tempScheme);
    
                    // Set channel 3 to position 1 and set the lights
                    Channel3Command = ShelfQueenCh3Position; 
                    SetLights(STOP);
    
                    // Keep the onboard LEDs off
                    RedLED.off();
                    GreenLED.off();
    
                    // Keep polling the radio
                    do{
                        PerLoopUpdates();
                    } while (RC_State == RC_SIGNAL_UNINITIALIZED);
    
                    // If we make it to here, a radio signal has been detected.
                    shelfQueenMode = false;                        // Exit shelf-queen mode
                    SetLightScheme(CurrentScheme);                 // Go back to CurrentScheme
    
                    if (DEBUG)
                    {                
                        PrintLine(80);
                        Serial.print(F("EXIT SHELF QUEEN MODE - REVERT TO SCHEME ")); Serial.println(CurrentScheme);
                        PrintLine(80);
                        Serial.println();             
                        Serial.println(); 
                    }
    
                    // Now proceed as normal...
                }
            }
            else
            {
                shelfQueenMode = false;
            }
        }

        if (DEBUG) DumpSystemInfo();                            // This puts some useful information to the Serial Port if we have Debug enabled
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

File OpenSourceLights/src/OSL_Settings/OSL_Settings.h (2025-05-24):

/* OSL_Settings.h   Settings file - a header file that defines many of the hardware elements of the OSL board
 * Source:          https://github.com/OSRCL/OSL_Original
 * Authors:         Luke Middleton
 *
 * These values should not need to be modified by general users. 
 *   
 */ 


#ifndef OSL_SETTINGS_H
#define OSL_SETTINGS_H

#include <Arduino.h>


// ------------------------------------------------------------------------------------------------------------------------------------------------------->>
// OPEN SOURCE LIGHTS (OSL) FIRMWARE VERSION NUMBER
// ------------------------------------------------------------------------------------------------------------------------------------------------------->>
    #define FIRMWARE_VERSION       "0.7.01"       	    	// version. Last update 5/24/2025
    


// ------------------------------------------------------------------------------------------------------------------------------------------------------->>
// PINS & HARDWARE DEFINITIONS
// ------------------------------------------------------------------------------------------------------------------------------------------------------->>	
	#define NumLights				      8					// How many light outputs do we have on this board



// ------------------------------------------------------------------------------------------------------------------------------------------------------->>
// FIRMWARE DEFINITIONS
// ------------------------------------------------------------------------------------------------------------------------------------------------------->>
	// There are 15 possible states a light can be in: 
	// - Mode 1, Mode 2, Mode 3, Mode 4, Mode 5 (all from Channel3 switch), 
	// - Forward, Reverse, Stop, Stop Delay, Brake (from Throttle Channel), 
	// - Right Turn, Left Turn, No Turn (from Turn Channel)
	// - Accelerating - special state that occurs on heavy acceleration (from Throttle channel)
	// - Decelerating - special state that occurs on heavy deceleration (from Throttle channel)
	#define NumStates                    15         		// Number of possible states
	// State definitions
	#define Mode1                         0         		// Channel 3 in 1st position
	#define Mode2                         1         		// Channel 3 in 2nd position
	#define Mode3                         2         		// Channel 3 in 3rd position
	#define Mode4                         3         		// Channel 3 in 4th position
	#define Mode5                         4         		// Channel 3 in 5th position        
	#define StateFwd                      5         		// Moving forward
	#define StateRev                      6         		// Moving backwards
	#define StateStop                     7         		// Stopped
	#define StateStopDelay                8         		// Stopped for a user-defined length of time
	#define StateBrake                    9         		// Braking
	#define StateRT                      10         		// Right turn
	#define StateLT                      11         		// Left turn
	#define StateNT                      12         		// "Neutral" turn, ie, no turn
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

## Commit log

2016-06-15 Add hardware files
    [OpenSourceLights_v17.brd, OpenSourceLights_v17.sch]
2016-06-15 Forgot to allow temporary turn signal action when just starting to move in reverse.
    [OpenSourceLights.ino]
2016-06-15 Correct drag brake behavior - it should apply when throtlte is at center but vehicle is still moving (DriveModePrev != Stop)
2016-06-17 Double the check time for detecting steering channel and channel 3. These functions only called once during setup.
2016-06-18 Added Nick's Excel file to auto-generate the light setup schemes.
    [OSL Light Setup Macro.xls]
2016-06-19 Updated the light setup Excel utility
    [OSL Light Setup Macro.xls, OSL Light Setup.xls]
2017-06-06 Adjust BLINK and SOFTBLINK to account for the potential that the light should not blink completely OFF but rather only to DIM, depending on the current Channel 3 setting.
2018-10-14 Correct typo that affected the left turn blinker, introduced 9/26/2018
    [Lights.ino]
2019-02-21 Add the option to average (smooth) RC commands if the user enables it on the AA_UserConfig.h file. Thanks to Wombii for code submission, for more see: https://www.rcgroups.com/forums/showthread.php?1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
2019-02-22 Set debug to default to false. The user can change it to whatever they want, but most of the time the onboard LEDs are sufficient for debugging. With recent versions of Arduino the F() macro causes c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
    [AA_UserConfig.h, OpenSourceLights.ino]
2019-06-02 Add a check when changing direction from forward to reverse or vice-versa, and only apply brake if a shift time has been specified or of double-tap reverse is true.
2021-03-13 Allow steering and channel 3 to be detected even after boot. Fix bug that prevented backfire lights from achieving full brightness (in fact, they were being overwritten by Wombii code which should ha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
    [AA_LIGHT_SETUP.ino, AA_UserConfig.h, Lights.ino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]
2021-03-13 We will also now need new Excel worksheets for those that prefer to use them. "OSL Light Setup_v3.xls" is for OSL firmware versions through 3.xx. It does not know anything about the new "No Turn" sta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
    [OSL Light Setup.xls, OSL Light Setup_v3.xls, OSL Light Setup_v4.xls]
2021-04-04 Complete rewrite. Interrupt-based radio reading, asynchronous light settings, simplified user configuration, intergrated libraries.
2021-04-08 Baudrate doesn't need to be a user setting, stick in OSL_Settings.h. We added some stuff to help us print a light scheme for debugging purposes.
    [OSL_Settings.h]
2021-04-08 Doesn't make sense to have change scheme mode timing related to turn signals, changed. Also moved some embedded constants to #defines.
    [OpenSourceLights.ino, RADIO_SETUP.ino]
2021-04-08 We can now print a clean-looking full scheme and it will look exactly the same as in code.
2021-04-09 Update the Excel utility
    [OSL Light Setup_v3.xls, OSL Light Setup_v4.xls, OSL Light Setup_v5.xls]
2021-05-30 If the light was previously in the dim state and we set it to blinking, we don't want it to blink from off to on, but rather from dim to on. Here we correct that. Note, this does not apply to SoftBli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
    [Lights.ino, OSL_LedHandler.cpp, OSL_LedHandler.h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]
2021-06-02 Fix minor bug in the Excel tool.
    [OSL Light Setup_v5.xls]
2023-11-08 Certain light settings might not be restored after loss of radio signal, this has been corrected.
    [Lights.ino, OSL_Settings.h, OpenSourceLights.ino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]
2024-03-25 Add alternate versions of blink and fast blink, called BLINK_ALT and FASTBLINK_ALT. These will blink at the same defined rate as their existing counterparts, but in an alternating fashion. For exampl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
    [OSL Light Setup_v5.xls, OSL Light Setup_v6.xls]
2025-05-24 Add "Safety Blink" functionality. Two Settings, "SAFETYBLINK" and "SAFETYBLINK_ALT" are provided, along with customized settings on the AA_UserConfig tab, to define a series of blinks (number and fre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
    [OSL Light Setup_v6.xls, OSL Light Setup_v7.xls]

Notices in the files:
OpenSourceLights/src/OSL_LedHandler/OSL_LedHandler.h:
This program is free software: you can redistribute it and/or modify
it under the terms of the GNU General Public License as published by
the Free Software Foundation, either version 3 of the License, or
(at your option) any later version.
